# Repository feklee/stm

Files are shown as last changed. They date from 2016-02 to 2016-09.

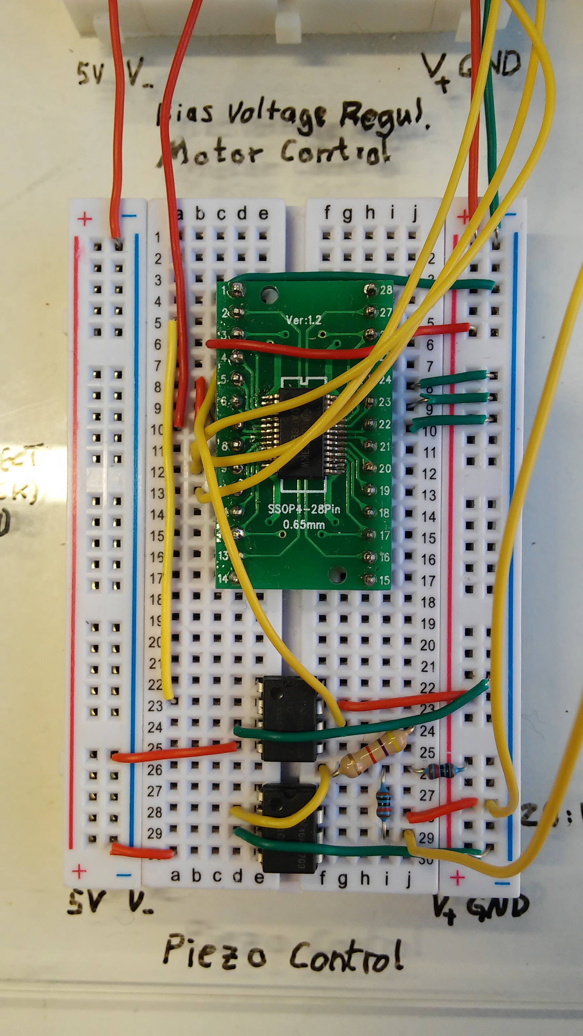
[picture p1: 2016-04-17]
approach/2016-04-16+02_electronics/piezo_control.jpg

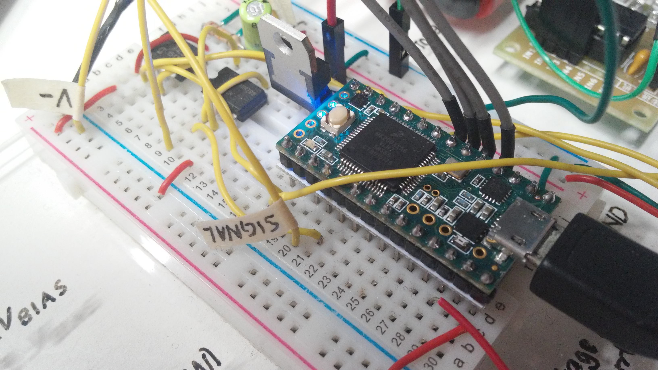
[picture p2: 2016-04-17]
approach/2016-04-16+02_electronics/main_board_2.jpg

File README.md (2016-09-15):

Introduction
============

Software and hardware source code for a DIY STM being developed at Fab Lab
Berlin.

For documentation, see: <https://wiki.fablab.berlin/index.php/STM>

Coding conventions
==================

  * Maximum line length: 80 characters

  * Comments in Markdown

  * JavaScript passes JSLint.

Thanks
======

  * [Dan Berard][4]: lots of suggestions by email, detailed documentation of
    his STM project

  * [hackerspaceshop][1]: donation of Teensy bluetooth serial module

  * [HU Berlin][2]: donation of graphite, platinum-iridium tips

  * [SparkMaker][3]: funding for parts

Legal
=====

Unless mentioned otherwise, stuff is licensed under the WTFPL version 2:
<http://www.wtfpl.net/>

[1]: https://hackerspaceshop.com/
[2]: https://www.hu-berlin.de/
[3]: http://sparkmaker.io/
[4]: https://dberard.com/

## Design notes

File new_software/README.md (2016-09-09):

Instructions
============

 1. Build and upload Arduino sketch `microcontroller` to Teensy 3 or
    compatible.

 2. List available serial ports for communication with the Teensy:

        $ cd server/
        $ npm start

 3. Start server, here with serial port `COM59`:

        $ npm start COM59

 4. Open index page in browser, in full screen mode on a 16:9 screen. Example
    URL (adapt to your system):

        http://localhost:8080

Build instructions
==================

First enter the directory `server/public`, then:

 1. Install Bower packages:

        $ bower install

 2. Compile CSS:

        $ sass -E utf-8 --update sass:stylesheets

    During development, you may use:

        $ sass -E utf-8 --watch sass:stylesheets

Coding conventions
==================

  * Maximum line length: 80 characters

  * Comments in Markdown

  * JavaScript passes JSLint.

Legal
=====

Unless mentioned otherwise, stuff is licensed under the WTFPL version 2:
<http://www.wtfpl.net/>

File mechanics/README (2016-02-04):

Settings for acrylics 3 mm with Trotec Speedy 400 80W
=====================================================

* Focus on orange plate (with film on bottom side): 3.4 mm

* Position inside stencil in lower left corner: 15.00 mm, 592.2 mm

-- 
The following settings are interpreted by EMACS, do not remove them.
Local Variables:
mode:text
fill-column:79
coding: utf-8
End:
Local IspellDict: american
LocalWords:  URN

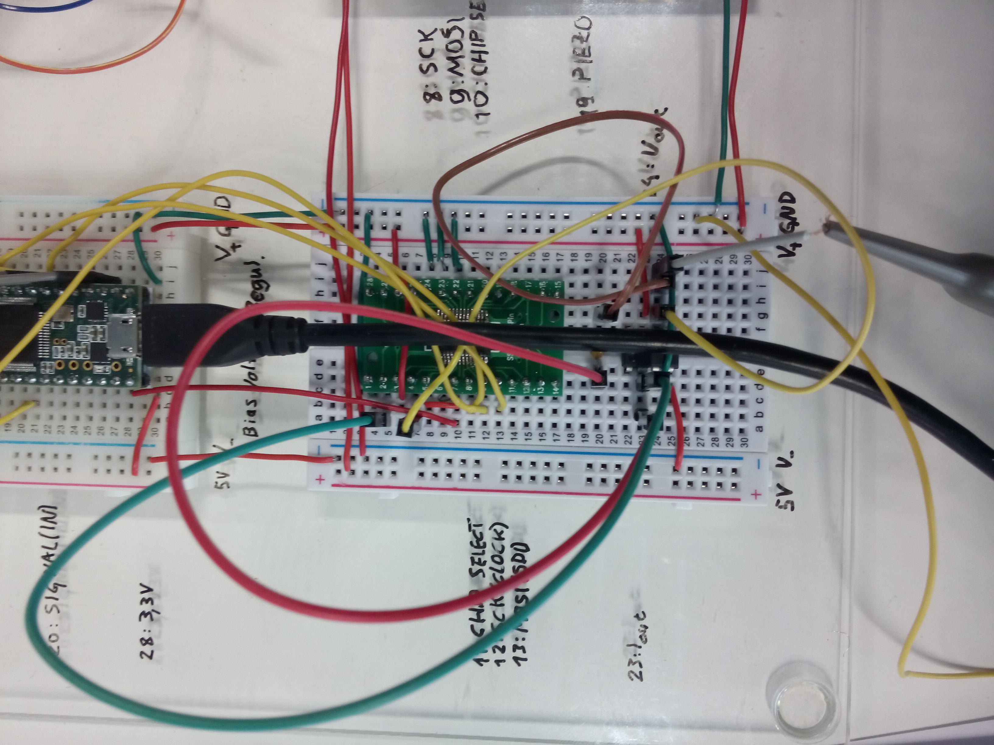
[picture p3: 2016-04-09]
approach/2016-04-09+02_electronics/new_dac.jpg

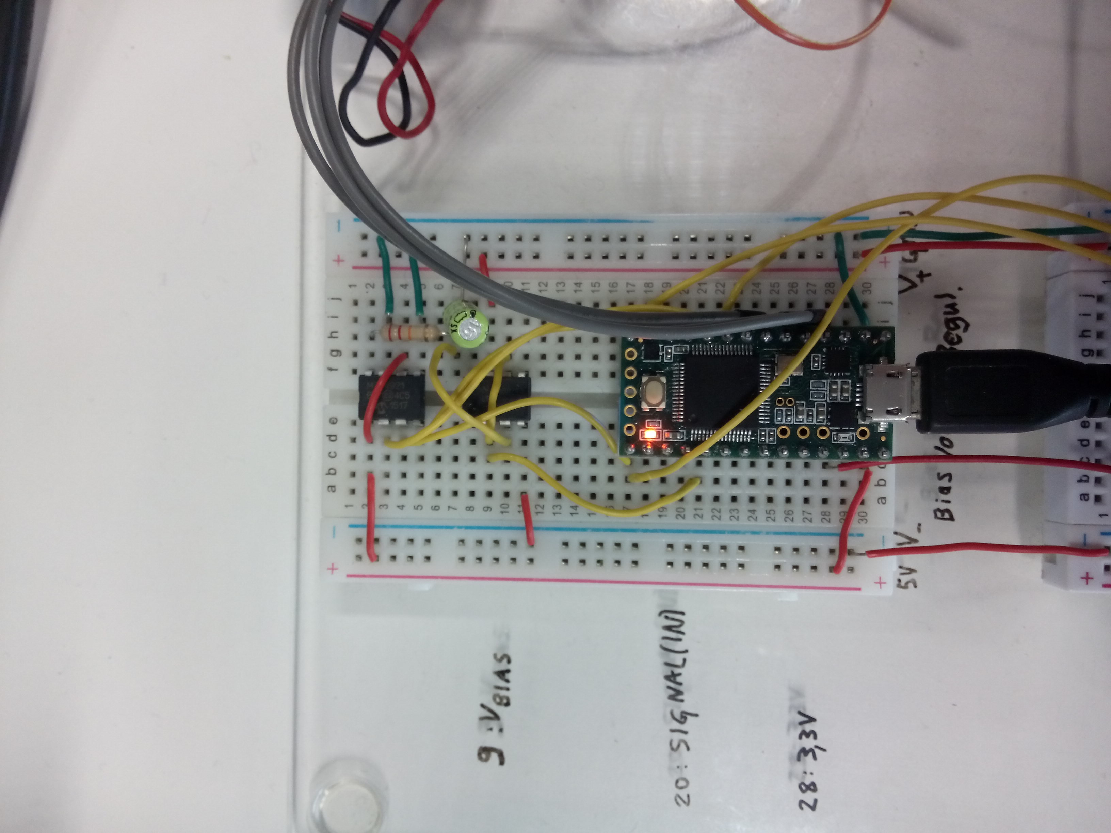
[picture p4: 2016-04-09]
approach/2016-04-09+02_electronics/bias_voltage_regulator.jpg

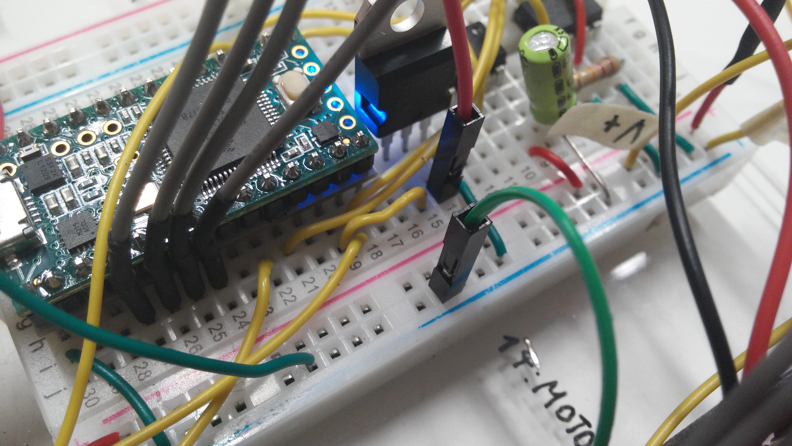
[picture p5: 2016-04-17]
approach/2016-04-16+02_electronics/main_board_1.jpg

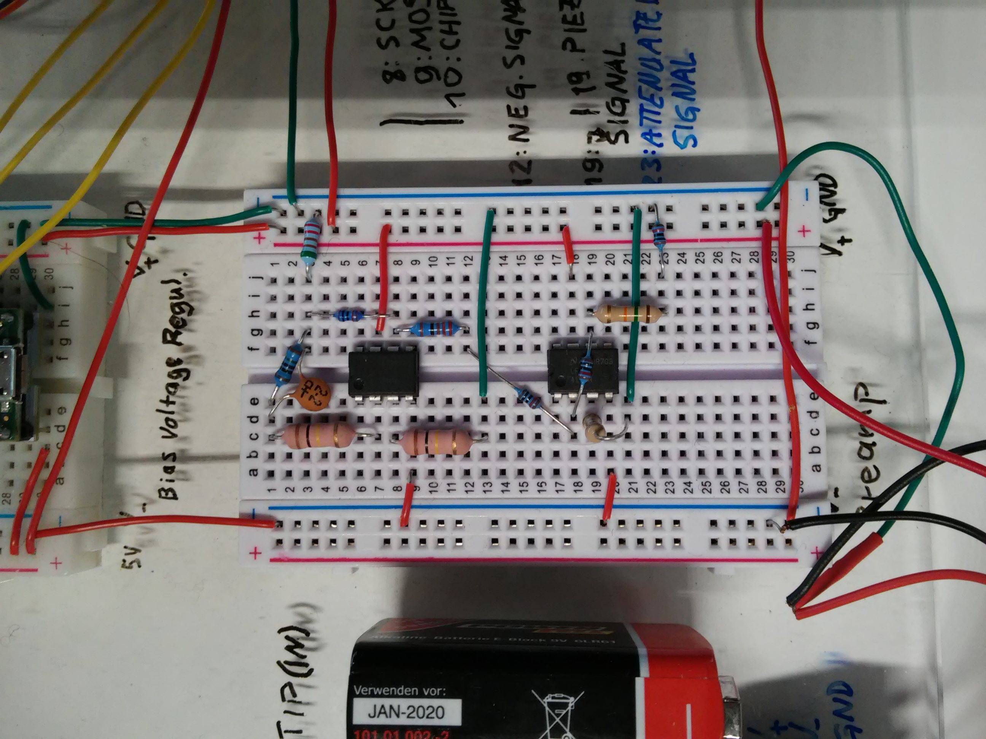
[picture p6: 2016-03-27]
approach/2016-03-20+01_electronics/preamp.jpg

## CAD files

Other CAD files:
approach/preamp_stripboard_wiring.3dm
mechanics/drawing.3dm

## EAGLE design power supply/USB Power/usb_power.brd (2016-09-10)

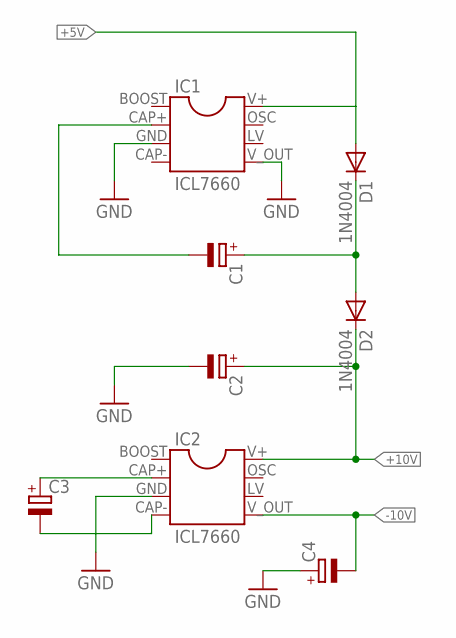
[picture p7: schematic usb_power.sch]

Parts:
C1, C2, C3, C4: CPOL-EUE2-4; E2-4
D1, D2: 1N4004; DO41-10
IC1, IC2: ICL7660; DIL08

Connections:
+5V: D1.A, IC1.V+ (8)
+10V: C2.+, D2.C, IC2.V+ (8)
-10V: C4.-, IC2.V_OUT (5)
GND: C2.-, C4.+, IC1.GND (3), IC1.V_OUT (5), IC2.GND (3)
unnamed: C1.-, IC1.CAP+ (2)
unnamed: C1.+, D1.C, D2.A
unnamed: C3.+, IC2.CAP+ (2)
unnamed: C3.-, IC2.CAP- (4)

Board: 2 copper layers, 8 parts (0 on the bottom side), 8 nets, no tracks yet.

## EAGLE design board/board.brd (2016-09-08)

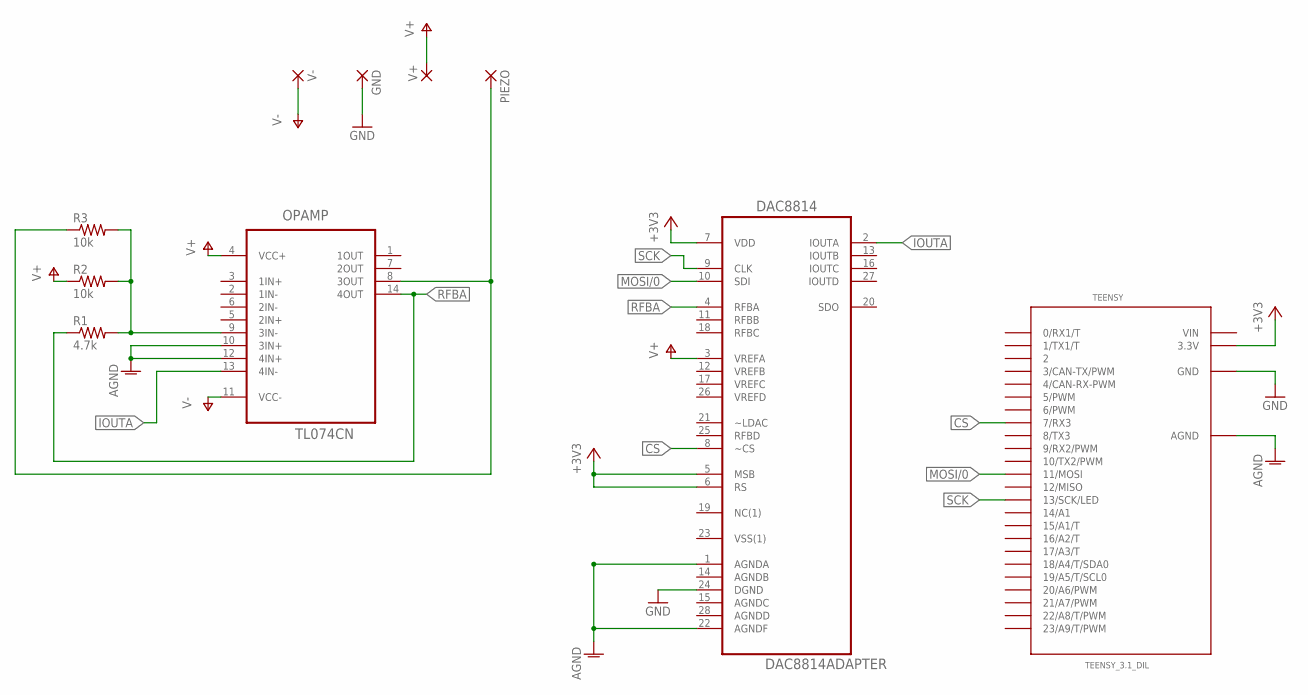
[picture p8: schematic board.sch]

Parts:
DAC8814: DAC8814ADAPTER; DIL28-6
GND: 1,6/0,8
OPAMP: TL074CN; DIP254P762X508-14
PIEZO: 1,6/0,8
R1: 4.7k; 0204/7
R2, R3: 10k; 0204/5
TEENSY: TEENSY_3.1_DIL; TEENSY3-DIL
V+: 1,6/0,8
V-: 1,6/0,8

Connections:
+3V3: DAC8814.5 (MSB), DAC8814.6 (RS), DAC8814.7 (VDD), TEENSY.3.3V
AGND: DAC8814.1 (AGNDA), DAC8814.22 (AGNDF), OPAMP.10 (3IN+), OPAMP.12 (4IN+), TEENSY.AGND
CS: DAC8814.8 (~CS), TEENSY.7 (7/RX3)
GND: DAC8814.24 (DGND), GND.1, TEENSY.GND
IOUTA: DAC8814.2 (IOUTA), OPAMP.13 (4IN-)
MOSI/0: DAC8814.10 (SDI), TEENSY.11 (11/MOSI)
unnamed: OPAMP.9 (3IN-), R1.2, R2.2, R3.2
unnamed: OPAMP.8 (3OUT), PIEZO.1, R3.1
RFBA: DAC8814.4 (RFBA), OPAMP.14 (4OUT), R1.1
SCK: DAC8814.9 (CLK), TEENSY.13 (13/SCK/LED)
V+: DAC8814.3 (VREFA), OPAMP.4 (VCC+), R2.1, V+.1
V-: OPAMP.11 (VCC-), V-.1
VIN: TEENSY.VIN

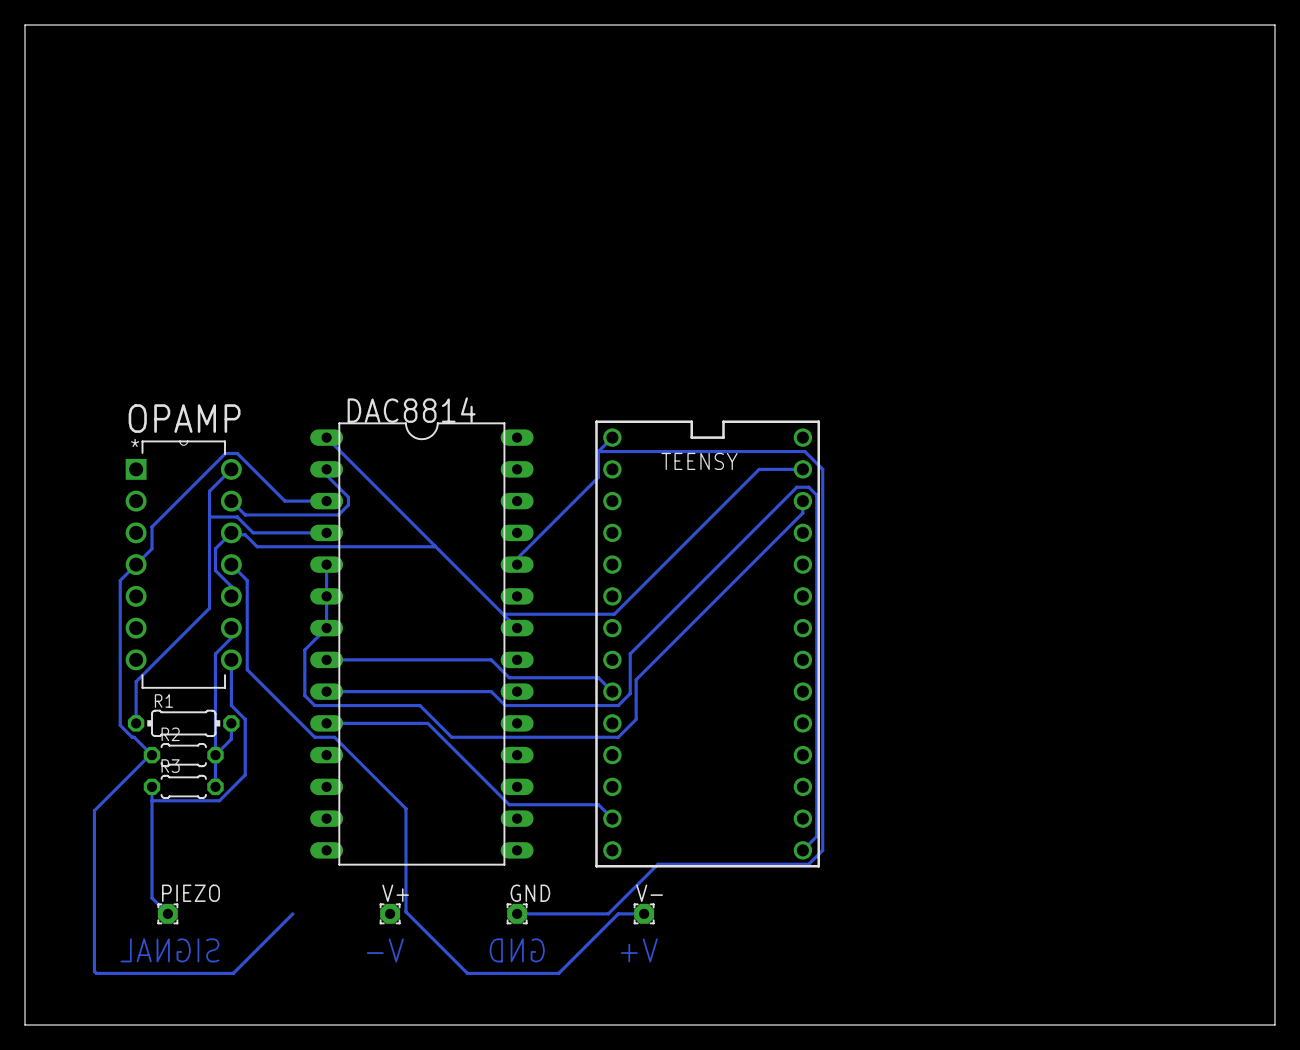
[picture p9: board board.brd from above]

Board: 2 copper layers, 100.0 x 80.0 mm, 10 parts (0 on the bottom side), 12 nets.

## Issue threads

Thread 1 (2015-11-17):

Teensy measures unstable output of opamp behind DAC

feklee, 2015-11-17:
Measurement with pin A3 (in 16 bit mode) vs. GND, Teensy LC.

Tested:

  * “Labornetzgerät Typ 5351.0”, “Ausgang 0-32V/0-2,5A” connected to GND and
    A3. Simple sketch:

        float readVoltageWithTeensyLC(int pin) {
          return analogRead(pin) * 3.3 / 0xffff;
        }

        void setup() {
          analogReadResolution(16);
        }

        void loop() {
          Serial.println(readVoltageWithTeensyLC(A3));
        }

    Results (V) are quite stable:

      + 0.5 V: 0.53, 0.53, 0.53, 0.53, 0.53, 0.53, 0.53, 0.53, 0.53, 0.54, etc.

      + 2.0 V: 2.00, 2.00, 2.00, 2.00, 2.00, 2.01, 2.00, 2.00, 2.00, 2.00, etc.

  * Simple voltage divider with three 10 kΩ resistors on paritally drained 9 V
    batteries: Result of 2.06 V matches closely what voltmeter measures
    (2.07 V).

    Same sketch as with “Labornetzgerät Typ 5351.0”.

  * Teensy on circuit, on pin A3 measuring output of opamp behind DAC:

        #include <SPI.h>

        #define BIAS_CHIP_SELECT_PIN 8

        float readVoltageWithTeensyLC(int pin) {
          return analogRead(pin) * 3.3 / 0xffff;
        }

        void setBiasVoltageFactor(float factor /* [0, 1] */) {
          const int iMax =  (1 << 12) - 1;
          int i = iMax * factor;
          byte b;

          digitalWrite(BIAS_CHIP_SELECT_PIN, LOW);
          SPI.beginTransaction(SPISettings(1400000, MSBFIRST, SPI_MODE0));
          b = highByte(i);
          b &= 0b00001111;
          b |= 0b00110000; // activates chip, sets gain to 1×
          SPI.transfer(b);
          b = lowByte(i);
          SPI.transfer(b);
          SPI.endTransaction();
          digitalWrite(BIAS_CHIP_SELECT_PIN, HIGH);
        }

        void setup() {
          pinMode(BIAS_CHIP_SELECT_PIN, OUTPUT);
          digitalWrite(BIAS_CHIP_SELECT_PIN, HIGH);
          SPI.begin();
          setBiasVoltageFactor(0.1 /* × 5 V */);
          analogReadResolution(16);
        }

        void loop() {
          Serial.println(readVoltageWithTeensyLC(A3));
        }

    Results (mV):

      + 0.1 × 5 V = 500 mV: 499.27, 499.22, 499.72, 499.02, 499.07, 498.86,
        499.17, 499.17, 500.83, 498.76, 497.91, 499.17, 499.12, 499.67, 498.41,
        499.27, 498.81, 498.56, 502.29, 499.72, 498.46, 499.52, 499.07, 498.21,
        499.17, 499.87, 499.32, 499.27, 499.27, 498.71, 499.07, 499.22, 497.35,
        498.21, 497.00, 497.30, 497.20, 498.86, 497.91 (stable)

      + 0.001 x 5 V = 5 mV: 6.45, 5.74, 6.29, 6.80, 6.04, 6.14, 5.99, 5.84,
        6.95, 6.45, 6.09, 5.79, 6.19, 5.79, 6.40, 5.94, 5.69, 6.60, 5.89, 6.95,
        6.04, 9.47, 5.89, 5.89, 5.79, 6.95, 6.34, 5.89, 6.65, 6.19, 7.15, 5.79,
        6.34 (not really stable)

   * Oscilloscope: Looks like there’s too much noise when measuring output of
     opamp behind DAC, set to 5 mV.

feklee, 2015-11-17:
Luka adjusted the oscilloscope probe setup, then suggested to add a 20 Hz low pass filter after the DAC, consisting of a resistor and a capacitor.

Formula: 1 / (2 π R C)

feklee, 2015-11-17:
RC filter installed (R = 22 kΩ, C = 0.47 μF ⇒ f = 16.9 Hz), but still unstable signal: 6.04, 5.74, 6.55, 9.37, 5.49, 5.99, …

According to the scope, after the filter, the amplitude of the noise is even higher.

feklee, 2015-11-17:
Ah, it need to be 50 mV, and that seems reasonably stable (mV): 51.11, 50.41, 51.26, 47.08, 50.41, 50.51, …

Closed 2015-11-17.

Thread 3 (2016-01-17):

What is the source of the noise when approaching?

feklee, 2016-01-17:
See attachment. What is the source of the noise?

Note: This is not the 50 Hz electric noise that the setup easily picks up from mains.

Ideas for investigation:

  * Is the noise also there when just measuring the signal? (it should not)

  * Is the noise also there when moving the piezo down, but not closely approaching?

  * Is the noise also there when running the code for moving the piezo down, but without physically moving it?
[approach_2.pdf](https://github.com/feklee/stm/files/93559/approach_2.pdf)

feklee, 2016-01-17:
First results: The noise is *not* visible when just monitoring the signal. It is visible when moving the piezo down, without being close to the surface (at least one screw turn away).

feklee, 2016-01-17:
See attachment. A delay of 100 µs after SPI communication with the DAC controlling the piezo makes the noise go away.

[no_noise_with_delay.pdf](https://github.com/feklee/stm/files/93573/no_noise_with_delay.pdf)

Closed 2016-01-17.

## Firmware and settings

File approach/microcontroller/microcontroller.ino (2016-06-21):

// Arduino / Teensy sketch
//
// For explanation of motor control, see:
// <http://www.instructables.com/id/BYJ48-Stepper-Motor>

#include <SPI.h>

#define MOTOR_PIN0 5
#define MOTOR_PIN1 4
#define MOTOR_PIN2 3
#define MOTOR_PIN3 2
#define MOTOR_ACTIVATION_PIN 9
#define SIGNAL_MEASURE_PIN A2
#define BIAS_MEASURE_PIN A3

// Hard coded in SPI library: 11 = MOSI, 13 = SCK
#define PIEZO_CHIP_SELECT_PIN 7
#define BIAS_CHIP_SELECT_PIN 8

#define MAX_PIEZO_POSITION 65535

struct SignalLogEntry {
  float signal;
  long piezoPosition;
};

long piezoPosition = 0;
const long signalLogMaxSize = 1024;
SignalLogEntry signalLog[signalLogMaxSize];
long signalLogHead = 0;
long signalLogSize = 0;

void step(boolean rotateClockwise) {
  static byte position = 0;
  sendPosition(position);
  position = nextPosition(position, rotateClockwise);
}

void activateMotor() {
  digitalWrite(MOTOR_ACTIVATION_PIN, HIGH);
}

void deactivateMotor() {
  digitalWrite(MOTOR_ACTIVATION_PIN, LOW);
}

long rotate(long stepsLeft, boolean rotateClockwise,
            float limitingSignal /* V */) {
  while (stepsLeft > 0 && signalIsInLimit(isMovingDown(rotateClockwise),
                                          limitingSignal)) {
    step(rotateClockwise);
    stepsLeft --;
    delay(1);
  }

  return stepsLeft;
}

void setBiasVoltageFactor(float factor /* [0, 1] */) {
  const int iMax =  (1 << 12) - 1;
  int i = iMax * factor;
  byte b;

  digitalWrite(BIAS_CHIP_SELECT_PIN, LOW);
  SPI.beginTransaction(SPISettings(1400000, MSBFIRST, SPI_MODE0));
  b = highByte(i);
  b &= 0b00001111;
  b |= 0b00110000; // activates chip, sets gain to 1×
  SPI.transfer(b);
  b = lowByte(i);
  SPI.transfer(b);
  SPI.endTransaction();
  digitalWrite(BIAS_CHIP_SELECT_PIN, HIGH);
}

// for easy parsing
String taggedSignalLogEntry(SignalLogEntry e) {
  return "#" + String(e.signal, 2).trim() + "|" +
    String(e.piezoPosition).trim();
}

float readVoltageWithTeensyLC(int pin) {
  return analogRead(pin) * 3.3 / 0xffff;
}

void setupPiezoSPI() {
  pinMode(PIEZO_CHIP_SELECT_PIN, OUTPUT);
  digitalWrite(PIEZO_CHIP_SELECT_PIN, HIGH);
}

void setupBiasRegulatorSPI() {
  pinMode(BIAS_CHIP_SELECT_PIN, OUTPUT);
  digitalWrite(BIAS_CHIP_SELECT_PIN, HIGH);
}

void setupMotor() {
  pinMode(MOTOR_ACTIVATION_PIN, OUTPUT);
  pinMode(MOTOR_PIN0, OUTPUT);
  pinMode(MOTOR_PIN1, OUTPUT);
  pinMode(MOTOR_PIN2, OUTPUT);
  pinMode(MOTOR_PIN3, OUTPUT);
}

void setup() {
  Serial.begin(9600);
  setupMotor();
  setupPiezoSPI();
  setupBiasRegulatorSPI();
  SPI.begin();
  setBiasVoltageFactor(0.015);
  analogReadResolution(16);
  prompt();
}

void prompt() {
  Serial.println("Enter command or `help`!");
}

void loop() {
  if (Serial.available() > 0) {
    interpretCommand(Serial.readString());
  }
}

String shift(String &s) {
  int i = s.indexOf(' ');
  String shifted, value;
  if (i == -1) {
    value = s;
    s = "";
    return value;
  }
  value = s.substring(0, i);
  s = s.substring(i + 1);
  return value;
}

void help() {
  Serial.println("Commands:\n"
                 "\n"
                 "  * set-bias <voltage (mV)>\n"
                 "\n"
                 "  * down <steps> [max. signal (V)]\n"
                 "\n"
                 "    Moves tip down while current signal is below maximum.\n"
                 "\n"
                 "  * up <steps> [min. signal (V)]\n"
                 "\n"
                 "    Moves tip up while current is above minimum.\n"
                 "\n"
                 "  * piezo-down <steps> [max. signal (V)] [step-increment]\n"
                 "\n"
                 "  * piezo-up <steps> [min. signal (V)] [step-increment]\n"
                 "\n"
                 "  * piezo-play\n"
                 "\n"
                 "    Plays a sound to test the piezo.\n"
                 "\n"
                 "  * woodpecker-down <max. signal (V)> <step-increment> "
                 "<piezo-step-increment>\n"
                 "\n"
                 "    Approaches automatically using the woodpecker method:\n"
                 "    motor down by `step-increment`, piezo down, if maximum "
                 "signal reached\n"
                 "    then stop or else move piezo up and repeat\n"
                 "\n"
                 "  * approach-and-keep <target signal (V)> <hover duration "
                 "(ms)>\n"
                 "\n"
                 "    Approaches using the woodpecker method. Then keeps the "
                 "position for the\n"
                 "    specified duration.\n"
                 "\n"
                 "  * approach-and-hover <target signal (V)> <hover duration "
                 "(ms)>\n"
                 "\n"
                 "    Approaches using the woodpecker method. Then hovers for "
                 "the specified duration,\n"
                 "    trying to maintain the signal by adjusting piezo "
                 "position.\n"
                 "\n"
                 "  * monitor-signal <duration (ms)> [delay (µs)]\n"
                 "\n"
                 "    Repeatedly prints the current signal (V).\n"
                 "\n"
                 "  * silently-monitor-signal <duration (ms)> [delay (µs)]\n"
                 "\n"
                 "    Repeatedly measures the current signal."
  );
}

void printElapsedTime(unsigned long startMillis) {
  Serial.print("(");
  Serial.print((millis() - startMillis) / 1000.);
  Serial.println(" s)");
}

void interpretCommand(String s) {
  Serial.print("> ");
  Serial.println(s);

  String command = shift(s);

  unsigned long startMillis = millis();

  clearSignalLog();

  if (command == "set-bias") {
    interpretSetBias(s);
  } else if (command == "down") {
    interpretDown(s);
  } else if (command == "up") {
    interpretUp(s);
  } else if (command == "piezo-down") {
    interpretPiezoDown(s);
  } else if (command == "piezo-up") {
    interpretPiezoUp(s);
  } else if (command == "piezo-play") {
    interpretPiezoPlay();
  } else if (command == "woodpecker-down") {
    interpretWoodpeckerDown(s);
  } else if (command == "approach-and-keep") {
    interpretApproachAndKeep(s);
  } else if (command == "approach-and-hover") {
    interpretApproachAndHover(s);
  } else if (command == "monitor-signal") {
    interpretMonitorSignal(s);
  } else if (command == "silently-monitor-signal") {
    interpretSilentlyMonitorSignal(s);
  } else {
    help();
  }

  printElapsedTime(startMillis);
}

void clearSignalLog() {
  int i;
  for (i = 0; i < signalLogSize; i ++) {
    signalLog[i] = {0, 0};
  }
  signalLogHead = 0;
  signalLogSize = 0;
}

void printLastSignals() {
  int i, j;
  String separator = "";
  Serial.print("Last signals (V): ");
  if (signalLogSize == 0) {
    Serial.println("nothing recorded");
    return;
  }
  for (i = -signalLogSize; i < 0; i++) {
    j = (signalLogSize + signalLogHead + i) % signalLogSize;
    Serial.print(separator);
    Serial.print(taggedSignalLogEntry(signalLog[j]));
    separator = ", ";
  }
  Serial.println("");
}

void printSummary(long stepsMoved = 0) {
  printLastSignals();
  Serial.print("Current signal (V): ");
  Serial.print(readSignal());
  Serial.print("; Steps moved: ");
  Serial.print(stepsMoved);
  Serial.print("; Piezo position (0-65535): ");
  Serial.print(piezoPosition);
  Serial.print("; Measured bias (mV): ");
  Serial.println(1000 * measuredBias());
}

long singleStepPiezo(long stepsLeft, boolean moveDown,
                     boolean limitSignal,
                     float limitingSignal /* V */,
                     long stepIncrement) {
  int direction = moveDown ? 1 : -1;

  while (stepsLeft > 0 &&
         (!limitSignal || signalIsInLimit(moveDown, limitingSignal))) {
    if (!stepPiezo(direction * stepIncrement)) {
      break;
    }
    stepsLeft -= stepIncrement;
  }
  return stepsLeft;
}

void interpretDown(String &parameters) {
  String s;
  long steps, stepsLeft;
  float maxSignal = 6; // max. voltage that Arduino can measure is 5V

  if ((s = shift(parameters)) == "") {
    help();
    return;
  }

  steps = s.toInt();

  if ((s = shift(parameters)) != "") {
    maxSignal = s.toFloat();
  }

  activateMotor();
  stepsLeft = rotate(steps, false, maxSignal);
  deactivateMotor();
  printSummary(steps - stepsLeft);
}

void interpretUp(String &parameters) {
  String s;
  long steps, stepsLeft;
  float minSignal = -1;

  if ((s = shift(parameters)) == "") {
    help();
    return;
  }

  steps = s.toInt();

  if ((s = shift(parameters)) != "") {
    minSignal = s.toFloat();
  }

  activateMotor();
  stepsLeft = rotate(steps, true, minSignal);
  deactivateMotor();
  printSummary(steps - stepsLeft);
}

long movePiezo(long stepsLeft, boolean moveDown,
               boolean limitSignal,
               float limitingSignal /* V */,
               long stepIncrement) {
  if (!limitSignal) {
    int direction = moveDown ? 1 : -1;
    stepPiezo(direction * stepsLeft);
    return 0;
  }

  return singleStepPiezo(stepsLeft, moveDown, limitSignal, limitingSignal,
                         stepIncrement);
}

void interpretPiezoDown(String &parameters) {
  String s;
  long steps, stepsLeft, stepIncrement = 1;
  float maxSignal = 0;
  boolean limitSignal = false;

  if ((s = shift(parameters)) == "") {
    help();
    return;
  }

  steps = s.toInt();

  if ((s = shift(parameters)) != "") {
    maxSignal = s.toFloat();
    limitSignal = true;
  }

  if ((s = shift(parameters)) != "") {
    stepIncrement = s.toInt();
  }

  stepsLeft = movePiezo(steps, true, limitSignal, maxSignal, stepIncrement);

  printSummary(steps - stepsLeft);
}

void interpretPiezoUp(String &parameters) {
  String s;
  long steps, stepsLeft, stepIncrement = 1;
  float minSignal = 0;
  boolean limitSignal = false;

  if ((s = shift(parameters)) == "") {
    help();
    return;
  }

  steps = s.toInt();

  if ((s = shift(parameters)) != "") {
    minSignal = s.toFloat();
    limitSignal = true;
  }

  if ((s = shift(parameters)) != "") {
    stepIncrement = s.toInt();
  }

  stepsLeft = movePiezo(steps, false, limitSignal, minSignal, stepIncrement);
  printSummary(steps - stepsLeft);
}

void positionPiezoForDuration(long desiredPosition, long duration /* ms */) {
  long startMillis = millis(), endMillis, waitMillis;
  piezoPosition = desiredPosition;
  positionPiezo();
  endMillis = millis();
  waitMillis = duration - (endMillis - startMillis);
  if (waitMillis <= 0) {
    return;
  }
  delay(waitMillis);
}

void interpretPiezoPlay() {
  float frequency = 440 /* Hz */;
  long duration = 1000 / frequency / 2 /* ms */,
    totalDuration = 2000 /* ms */;

  for (long i = 0; i < totalDuration / (2 * duration); i ++) {
    positionPiezoForDuration(0xffff, duration);
    positionPiezoForDuration(0, duration);
  }

  printSummary();
}

void interpretSetBias(String &parameters) {
  String s;

  if ((s = shift(parameters)) == "") {
    help();
    return;
  }

  setBiasVoltageFactor(s.toFloat() / 3300);
  printSummary();
}

void printSignal(float signal, boolean flush = false) {
  static boolean hasBeenFlushed = true;

  if (flush) {
    Serial.println();
    hasBeenFlushed = true;
    return;
  }

  Serial.print(hasBeenFlushed ? "" : ", ");
  Serial.print(signal);
  hasBeenFlushed = false;
}

boolean signalIsInLimit(boolean isMovingDown, float limitingSignal) {
  float signal = readAndLogSignal(); // always log

  if (isMovingDown) {
    return signal < limitingSignal;
  } else {
    return signal > limitingSignal;
  }
}

boolean stepPiezo(int step) {
  if ((piezoPosition == 0xffff && step > 0) ||
      (piezoPosition == 0 && step < 0)) {
    return false; // not stepped
  }
  piezoPosition += step;
  if (piezoPosition < 0) {
    piezoPosition = 0;
  } else if (piezoPosition > 0xffff) {
    piezoPosition = 0xffff;
  }

  positionPiezo();
  return true;
}

// Voltage, proportional to tip current.
float readSignal() /* V */ {
  return readVoltageWithTeensyLC(SIGNAL_MEASURE_PIN);
}

void logSignal(float signal) {
  signalLog[signalLogHead] = {signal, piezoPosition};

  signalLogHead ++;
  if (signalLogHead >= signalLogMaxSize) {
    signalLogHead = 0;
  }

  signalLogSize =
    (signalLogSize < signalLogMaxSize) ?
    signalLogSize + 1 :
    signalLogMaxSize;
}

float readAndLogSignal() {
  float signal = readSignal();
  logSignal(signal);
  return signal;
}

boolean isMovingDown(boolean rotateClockwise) {
  return !rotateClockwise;
}

void sendPosition(byte position) {
  switch (position) {
  case 0:
    setMotorPins(LOW, LOW, LOW, HIGH);
    break;
  case 1:
    setMotorPins(LOW, LOW, HIGH, HIGH);
    break;
  case 2:
    setMotorPins(LOW, LOW, HIGH, LOW);
    break;
  case 3:
    setMotorPins(LOW, HIGH, HIGH, LOW);
    break;
  case 4:
    setMotorPins(LOW, HIGH, LOW, LOW);
    break;
  case 5:
    setMotorPins(HIGH, HIGH, LOW, LOW);
    break;
  case 6:
    setMotorPins(HIGH, LOW, LOW, LOW);
    break;
  case 7:
    setMotorPins(HIGH, LOW, LOW, HIGH);
    break;
  }
}

void setMotorPins(byte val0, byte val1, byte val2, byte val3) {
  digitalWrite(MOTOR_PIN0, val0);
  digitalWrite(MOTOR_PIN1, val1);
  digitalWrite(MOTOR_PIN2, val2);
  digitalWrite(MOTOR_PIN3, val3);
}

byte nextPosition(byte position, boolean rotateClockwise) {
  position += (rotateClockwise ? 1 : -1);
  return position & 7;
}

void positionPiezo() {
  byte dacChannel = 0;
  digitalWrite(PIEZO_CHIP_SELECT_PIN, LOW);
  SPI.beginTransaction(SPISettings(1400000, MSBFIRST, SPI_MODE0));
  SPI.transfer(dacChannel);
  SPI.transfer16(piezoPosition);
  SPI.endTransaction();
  digitalWrite(PIEZO_CHIP_SELECT_PIN, HIGH);
}

float measuredBias() /* V */ {
  return readVoltageWithTeensyLC(BIAS_MEASURE_PIN);
}

void movePiezoAllTheWayUp() {
  movePiezo(0xffff, false, false, 0, 1);
}

void woodpeckerDown(float maxSignal, long stepIncrement,
                    long piezoStepIncrement) {
  long stepsLeft;
  boolean piezoWasStoppedBeforeReachingEnd;

  activateMotor();

  Serial.println("After each motor step, the log of signals is cleared.");
  while (true) {
    Serial.print("Signal before next motor step (V): ");
    Serial.print(readSignal());
    Serial.println();

    movePiezoAllTheWayUp();
    rotate(stepIncrement, false, maxSignal);
    clearSignalLog();
    stepsLeft = movePiezo(0xffff, true, true, maxSignal, piezoStepIncrement);
    piezoWasStoppedBeforeReachingEnd = stepsLeft >= piezoStepIncrement;

    // Breaks loop if signal is strong enough and the motor has positioned the
    // piezo in a position where there is good room to move the tip up and down
    // with the piezo.
    if (piezoWasStoppedBeforeReachingEnd && piezoPosition > 0x7fff) {
      break;
    }
  }

  deactivateMotor();
}

void interpretWoodpeckerDown(String &parameters) {
  String
    s1 = shift(parameters),
    s2 = shift(parameters),
    s3 = shift(parameters);
  long stepIncrement, piezoStepIncrement;
  float maxSignal;

  if (s3 == "") {
    help();
    return;
  }

  maxSignal = s1.toFloat();
  stepIncrement = s2.toInt();
  piezoStepIncrement = s3.toInt();

  woodpeckerDown(maxSignal, stepIncrement, piezoStepIncrement);

  printSummary();
}

void keep(unsigned long duration) {
  unsigned long startMillis = millis(), endMillis;

  endMillis = startMillis + duration;
  while (millis() < endMillis) {
    Serial.println(readAndLogSignal());
    delayMicroseconds(50000);
  }
}

void approachAndKeep(float targetSignal, unsigned long keepDuration) {
  woodpeckerDown(targetSignal, 1, 100);
  Serial.println("Approached. Keeping position.");
  keep(keepDuration);
}

void interpretApproachAndKeep(String &parameters) {
  String
    s1 = shift(parameters),
    s2 = shift(parameters);
  unsigned long keepDuration;
  float targetSignal;

  if (s2 == "") {
    help();
    return;
  }

  targetSignal = s1.toFloat();
  keepDuration = s2.toInt();

  approachAndKeep(targetSignal, keepDuration);

  printSummary();
}

void hover(float targetSignal, unsigned long duration) {
  unsigned long startMillis = millis(), endMillis,
    lastPrintMillis = millis(), m;

  endMillis = startMillis + duration;
  while ((m = millis()) < endMillis) {
    if (m - lastPrintMillis > 50) { // only print in intervals
      Serial.println(readAndLogSignal());
      lastPrintMillis = m;
    }
    if (readSignal() > targetSignal) {
      stepPiezo(-1);
    } else if (readSignal() < targetSignal) {
      stepPiezo(1);
    }
  }
}

void approachAndHover(float targetSignal, unsigned long hoverDuration) {
  woodpeckerDown(targetSignal, 1, 100);
  Serial.println("Approached. Approaching again, with higher resolution.");
  movePiezoAllTheWayUp();
  movePiezo(0xffff, true, true, targetSignal, 10);
  Serial.println("Hovering.");
  hover(targetSignal, hoverDuration);
}

void interpretApproachAndHover(String &parameters) {
  String
    s1 = shift(parameters),
    s2 = shift(parameters);
  unsigned long hoverDuration;
  float targetSignal;

  if (s2 == "") {
    help();
    return;
  }

  targetSignal = s1.toFloat();
  hoverDuration = s2.toInt();

  approachAndHover(targetSignal, hoverDuration);

  printSummary();
}

void monitorSignal(unsigned long duration /* ms */,
                   unsigned long measurementDelay /* µs */,
                   boolean signalShouldBePrinted) {
  unsigned long startMillis = millis(), endMillis;

  endMillis = startMillis + duration;
  while (millis() < endMillis) {
    if (signalShouldBePrinted) {
      Serial.println(readSignal());
    } else {
      readAndLogSignal();
    }
    delayMicroseconds(measurementDelay);
  }

  printSummary();
}

void interpretMonitorSignal(String &parameters) {
  String s;
  unsigned long duration, measurementDelay = 100000;

  if ((s = shift(parameters)) == "") {
    help();
    return;
  }
  duration = s.toInt();

  if ((s = shift(parameters)) != "") {
    measurementDelay = s.toInt();
  }

  monitorSignal(duration, measurementDelay, true);
}

void interpretSilentlyMonitorSignal(String &parameters) {
  String s;
  unsigned long duration, measurementDelay = 100000;

  if ((s = shift(parameters)) == "") {
    help();
    return;
  }
  duration = s.toInt();

  if ((s = shift(parameters)) != "") {
    measurementDelay = s.toInt();
  }

  monitorSignal(duration, measurementDelay, false);
}

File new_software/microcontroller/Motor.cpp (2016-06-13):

// For explanation of motor control, see:
// <http://www.instructables.com/id/BYJ48-Stepper-Motor>

#include <Arduino.h>
#include "util.hpp"
#include "Motor.hpp"

void Motor::setPins(byte val0, byte val1, byte val2, byte val3) {
  digitalWrite(pins_[0], val0);
  digitalWrite(pins_[1], val1);
  digitalWrite(pins_[2], val2);
  digitalWrite(pins_[3], val3);
}

void Motor::sendPosition() {
  switch (position_) {
  case 0:
    setPins(LOW, LOW, LOW, HIGH);
    break;
  case 1:
    setPins(LOW, LOW, HIGH, HIGH);
    break;
  case 2:
    setPins(LOW, LOW, HIGH, LOW);
    break;
  case 3:
    setPins(LOW, HIGH, HIGH, LOW);
    break;
  case 4:
    setPins(LOW, HIGH, LOW, LOW);
    break;
  case 5:
    setPins(HIGH, HIGH, LOW, LOW);
    break;
  case 6:
    setPins(HIGH, LOW, LOW, LOW);
    break;
  case 7:
    setPins(HIGH, LOW, LOW, HIGH);
    break;
  }
  delay(1); // positions sent in too fast succession → motor hangs
}

void Motor::stepDown() {
  position_ = (position_ - 1) & 7;
  sendPosition();
}

void Motor::stepUp() {
  position_ = (position_ + 1) & 7;
  sendPosition();
}

void Motor::activate() {
  digitalWrite(activationPin_, HIGH);
}

void Motor::deactivate() {
  digitalWrite(activationPin_, LOW);
}

void Motor::setup() {
  for (int i = 0; i < 4; i ++) {
    pinMode(pins_[i], OUTPUT);
  }
  pinMode(activationPin_, OUTPUT);
}

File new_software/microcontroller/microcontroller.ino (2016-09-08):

#include <SPI.h>
#include <ArduinoJson.h>
#include "IdleMode.hpp"
#include "ScanMode.hpp"
#include "ApproachMode.hpp"
#include "RetractMode.hpp"
#include "PiezoPlayMode.hpp"
#include "TipPositionLog.hpp"
#include "ModeChain.hpp"
#include "util.hpp"

static Current current;
static TipPositionLog tipPositionLog;
static BiasVoltage biasVoltage;
static Piezo piezo;
static Motor motor;
static IdleMode idleMode;
static ScanMode scanMode(tipPositionLog, current, piezo);
static ApproachMode approachMode(motor, biasVoltage, current, piezo,
                                 tipPositionLog);
static RetractMode retractMode(motor, biasVoltage, current, piezo,
                               tipPositionLog);
static PiezoPlayMode piezoPlayMode(piezo);
static Mode *mode = &idleMode;
static ModeChain modeChain(idleMode);

void setup() {
  Serial.begin(115200);
  analogReadResolution(16);

  biasVoltage.setup();
   piezo.setup();
  motor.setup();

  SPI.begin();
}

void switchMode(Mode &newMode) {
  mode = &newMode;
  mode->reset();
  printValue("newMode", mode->name());
}

Mode &modeFromNode(JsonObject &node) {
  String name = node["mode"].asString();
  if (name == scanMode.name()) {
    scanMode.setSideLen(node["sideLen"]);
    scanMode.setMaxAdjustmentSteps(node["maxAdjustmentSteps"]);
    scanMode.setAdjustmentDelta(node["adjustmentDelta"]);
    scanMode.setTargetSignal(node["targetSignal"]);
    return scanMode;
  } else if (name == approachMode.name()) {
    approachMode.setTargetSignal(node["targetSignal"]);
    approachMode.setFinePiezoStepSize(node["finePiezoStepSize"]);
    approachMode.setCoarsePiezoStepSize(node["coarsePiezoStepSize"]);
    return approachMode;
  } else if (name == retractMode.name()) {
    retractMode.setTargetSignal(node["targetSignal"]);
    return retractMode;
  } else if (name == piezoPlayMode.name()) {
    return piezoPlayMode;
  } else {
    return idleMode;
  }
}

void interpretSerialInput(const String &s) {
  const int maxStringLength = 512;
  char t[maxStringLength + 1];
  const int maxNumberOfExpectedProperties = 20;
  const int maxChainSize = ModeChain::maxSize;
  const int bufferSize =
    JSON_ARRAY_SIZE(maxChainSize) +
    maxChainSize * maxNumberOfExpectedProperties;
  StaticJsonBuffer<bufferSize> jsonBuffer;

  if (s.length() > maxStringLength) {
    printError("Input too long");
    return;
  }

  strncpy(t, s.c_str(), s.length());

  JsonArray &root = jsonBuffer.parseArray(t);
  if (!root.success()) {
    printError("Parsing JSON failed");
    return;
  }

  modeChain.clear();
  for (unsigned int i = 0; i < root.size(); i ++) {
    modeChain.append(modeFromNode(root[i]));
  }
  switchMode(modeChain.next());
}

void loop() {
  bool continueStepping;

  if (Serial.available() > 0) {
    interpretSerialInput(Serial.readString());
  }
  continueStepping = mode->step();
  if (!continueStepping) {
    switchMode(modeChain.next());
  }
  biasVoltage.print();
  current.measure();
  current.print();
}

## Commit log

2015-10-22 Added mechanics plans
    [2015-10-18_test.3dm, 2015-10-21_test.3dm]
2015-10-24 Add new top plate; Update code (CLI)
    [2015-10-21_test.3dm]
2015-10-27 Add piezo
    [beta_test.3dm]
2015-11-12 Add code for setting bias voltage (not functional)
2015-11-12 Use SPI library (untested)
2015-11-13 Add TINA opamp circuit schema
2015-11-14 Change chip select pin; Remove unneeded schema
2015-11-14 Add command to set bias voltage
2015-11-15 Add voltage divider
2015-11-15 Simulate gap by resistor
2015-11-15 Update voltage scaling; Replace opamp
    [approach.ino]
2015-11-16 Add alternative preamp circuit (untested)
2015-11-16 Add voltage inversion to John's circuit
2015-11-17 Add RC filter
2015-11-17 Change default bias voltage to 50 mV
2015-11-19 Add fixes (still bugs with logging)
    [approach.ino]
2015-11-20 Fix: monitoring should not log
    [approach.ino]
2016-01-15 Always show log of last signals; Fix wp approach
    [approach.ino]
2016-01-17 Add delay to dampen SPI noise
    [approach.ino]
2016-01-28 Add PC interface; Improce mechanics; Reorder files
    [beta_test.3dm]
2016-01-28 Fix: Monitored signal not printed correctly
    [microcontroller.ino]
2016-01-30 Reverse order of printed signals; Adjust scale
    [pc.pde]
2016-01-31 Fix: Output of signals and tagging
    [microcontroller.ino]
2016-02-04 New mechanics design for 3 mm acrylics
    [beta_test.3dm]
2016-02-04 Simplify design for easier & more precise cutting
    [beta_test.3dm]
2016-02-06 Add basic drawings for mech, as requested by Luka
    [2016-02-06+01_for_Luka.3dm]
2016-02-09 Clean up; Start with wiring diagram
    [2015-10-18_test.3dm, 2015-10-21_test.3dm, 2016-02-06+01_for_Luka.3dm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]
2016-02-09 Changed rubber band mount
    [drawing.3dm]
2016-02-09 Update wiring diagram
    [drawing.3dm, preamp_stripboard_wiring.3dm]
2016-02-12 Change drawing mode, update wiring
    [drawing.3dm, preamp_stripboard_wiring.3dm]
2016-02-13 Add clear button
2016-03-13 Fix order of gui element creation
    [pc.pde]
2016-03-20 Fix: Serial port menu obscured
    [pc.pde]
2016-03-27 Documentation for switch of piezo controller
2016-04-09 2016-04-09_electronics pictures
    On the new dac breadboard: moved 2 cables up, making space for second op amp.
    This is needed for "bipolar output". In the datasheet of the DAC 8814, the
    needed circuit is described on p. 21. (For non-multiplying DACs only one op is
    needed)
2016-04-13 Add support for new DAC; Screenshot of new circuit
2016-04-17 Add transistor to turn motor on/off
2016-04-17 Add photos of current setup
2016-04-25 Rename to avoid confusion; Tweak aproach
    [microcontroller.ino]
2016-04-27 Switch to TL1074 opamp circuit
2016-05-21 Change Motor activation from fried pin 10 => 9
2016-06-08 10V => 3V - Tina Schematics
2016-06-09 Move simulation to Teensy
2016-06-09 Fix: z not randomly walking
    [microcontroller.ino]
2016-06-10 Add proper error handling; Make fader more robust
    [microcontroller.ino]
2016-06-11 Fix: z position only updated once per chunk
    [Position.cpp]
2016-06-12 Move pin declaration into class
2016-06-12 Implement motor control
2016-06-12 Add bias voltage control
2016-06-12 Fix: Bias voltage not correctly measured
    [ApproachMode.cpp, microcontroller.ino]
2016-06-12 Make approach with motor work
2016-06-14 Add current log to approach
2016-06-14 Update naming; Add current log to retract mode
2016-06-14 Replace current log by tip position log
    [ApproachMode.cpp, RetractMode.cpp, TipPositionLog.cpp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]
2016-06-14 Retract with piezo prior to retracting with motor
2016-06-14 Add message on mode switch
2016-06-14 Add chaining of modes
2016-06-14 Mix in current signal instead of z
2016-06-15 Simplify: ModeQueue → ModeChain
2016-06-15 boolean → bool
2016-06-15 Implement basic constant current mode (tip adj.)
2016-06-15 Fix: Sometimes bad JSON with values 0.0.01 for ex.
    [TipPositionLog.cpp]
2016-06-15 Fix delta displacement, STM error reporting
    [Piezo.cpp]
2016-06-15 Switch back to constant height mode
2016-06-15 Make target current signal configurable
2016-06-15 targetCurrentSignal → targetSignal
2016-06-18 Compute simulated scan; Tweak
    [drawing.3dm]
2016-06-20 Change order of motor pins
2016-06-20 Adapt bias voltage to 3.3 V
2016-06-23 Change IP of web socket
2016-06-24 Fix flushing (approach, retract); Speed up
    [ApproachMode.cpp, RetractMode.cpp]
2016-07-05 Switch direction of fader
2016-09-01 Name button more clearly
2016-09-05 Pretty print JSON
2016-09-06 Add draft of board layout
    [board.sch]
2016-09-08 Add and arrange components for controlling piezo
    [board.brd, board.sch]
2016-09-08 Add missing connections
    [board.brd, board.sch]
2016-09-09 Add stop button; Fix SCSS UTF-8 issue
2016-09-10 Light blue → light gray
2016-09-10 USB power schematics
    [usb_power.brd, usb_power.sch]
2016-09-12 Add axis for current signal
2016-09-13 Scale x-axis to microseconds
2016-09-14 Add fit width button
2016-09-15 Add preamp based on Dan's design
    [preamp.sch]
